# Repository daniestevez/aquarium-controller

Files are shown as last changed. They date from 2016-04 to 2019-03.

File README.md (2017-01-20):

# aquarium-controller
Arduino-based Aquarium controller

[More information](http://destevez.net/electronics-projects/arduino-aquarium-controller/)

Libraries required for the Arduino software:

* Time, DS1307RTC from http://playground.arduino.cc/Code/Time
* Timer from http://playground.arduino.cc/Code/Timer
* Timezone from https://github.com/JChristensen/Timezone
* Keypad from http://playground.arduino.cc/Code/Keypad
* U8glib from https://github.com/olikraus/u8glib
* OneWireNoResistor from https://github.com/bigjosh/OneWireNoResistor

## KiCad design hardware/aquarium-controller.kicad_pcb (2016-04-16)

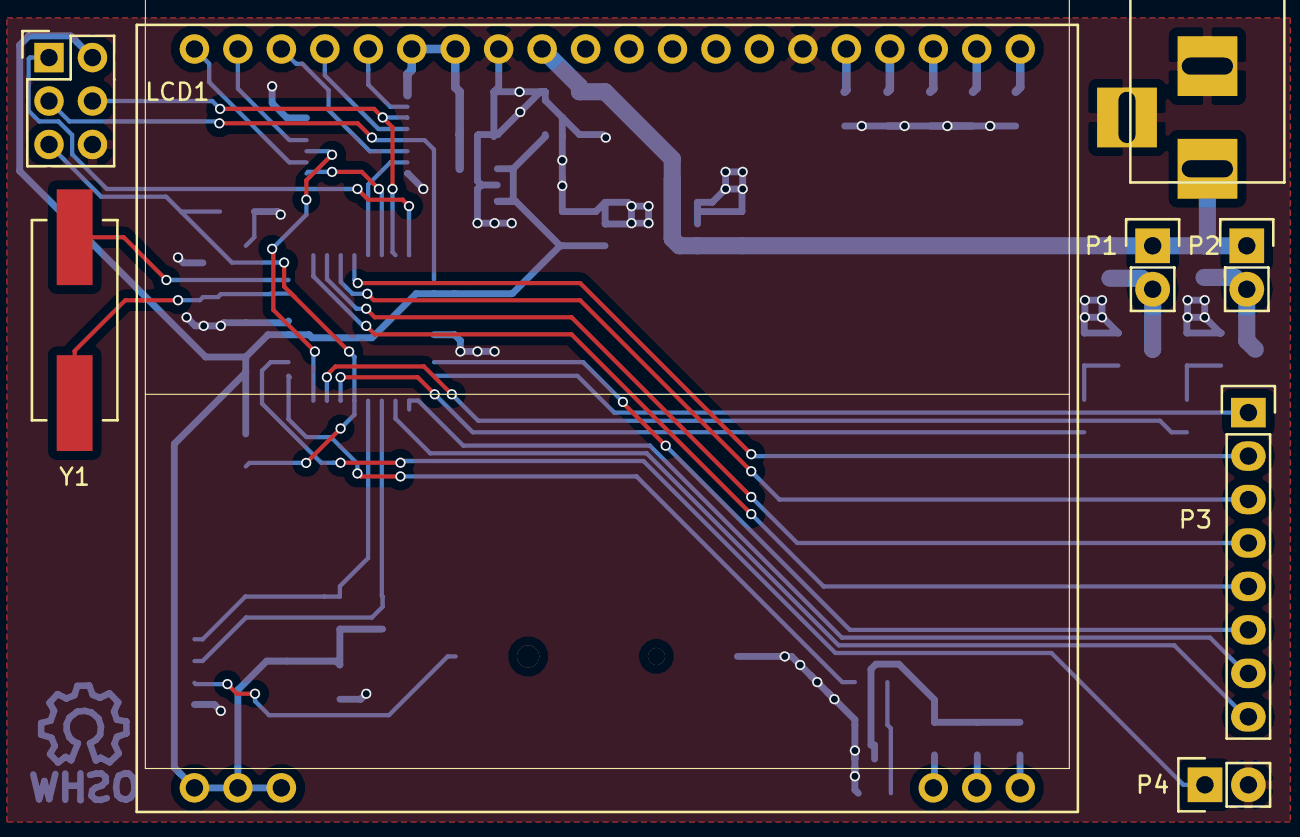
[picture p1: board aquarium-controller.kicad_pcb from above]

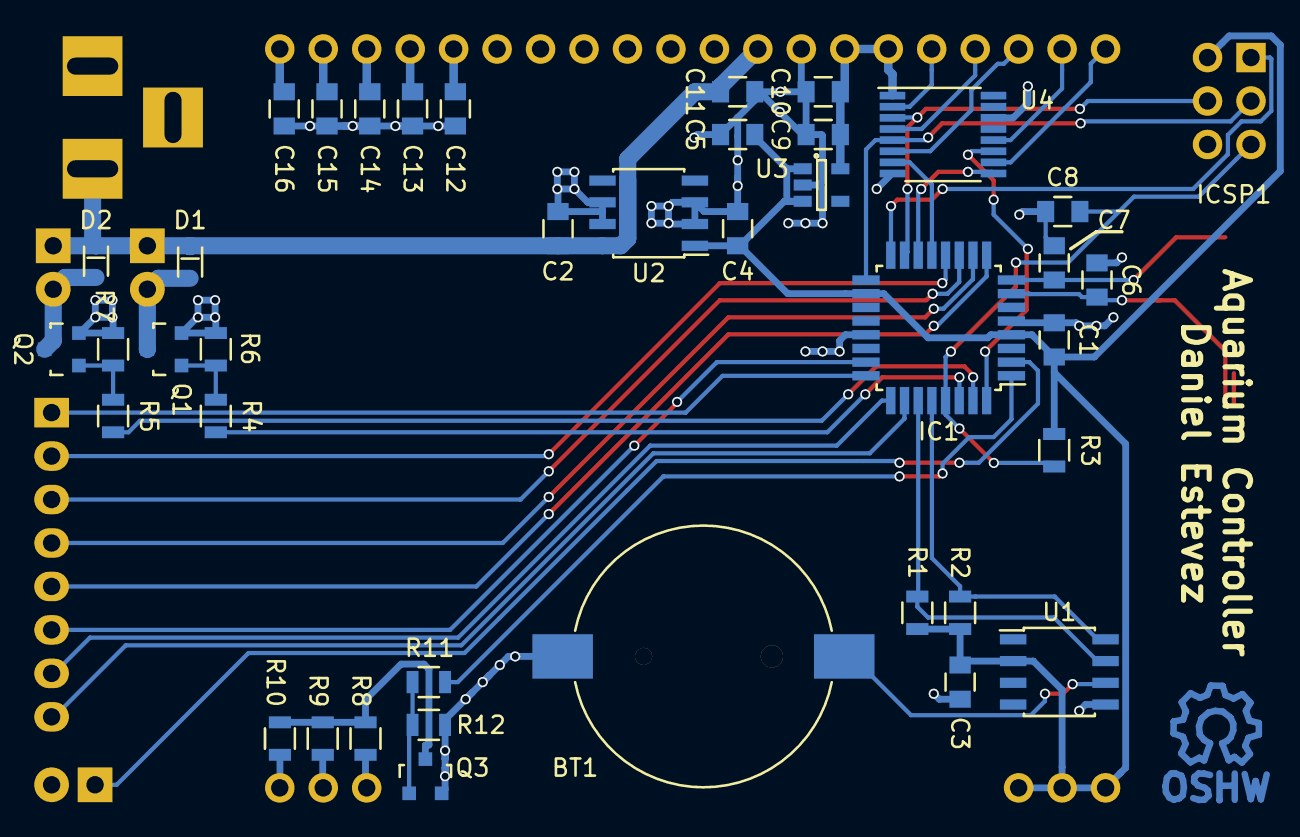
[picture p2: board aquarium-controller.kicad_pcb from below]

Board: 2 copper layers, 47 parts (39 on the bottom side), 47 nets.

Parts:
BT1: Battery; BC501SM
C1, C3, C4, C8, C10: 100n; C_0805
C2: 330n; C_0805
C5, C9, C11, C12, C13, C14, C15, C16: 1u; C_0805
C6, C7: 22p; C_0805
CON1: BARREL_JACK
D1, D2: DB2J20900L; SMini2-F5-B
IC1: ATMEGA328PB; TQFP-32_7x7mm_Pitch0.8mm
ICSP1: AVR-ISP-6; Pin_Header_Straight_2x03
LCD1: DOGM128-6; LED55X46
P1, P2, P4: CONN_01X02; Socket_Strip_Straight_1x02
P3: CONN_01X08; Socket_Strip_Straight_1x08
Q1, Q2, Q3: 2N7002E; SOT-23
R1, R2, R3: 10k; R_0805
R4, R5, R8, R9, R10, R11: 100; R_0805
R6, R7, R12: 100K; R_0805
U1: DS3231M; SOIC-8_3.9x4.9mm_Pitch1.27mm
U2: L78L05ACD; SOIC-8_3.9x4.9mm_Pitch1.27mm
U3: MIC5504; SOT-23-5
U4: 4050; TSSOP-16_4.4x5mm_Pitch0.65mm
Y1: 16MHz; Crystal_HC49-SD_SMD

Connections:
+3V3: C9.1, C10.1, LCD1.34, LCD1.35, U3.5, U4.1
+5V: C1.1, C3.2, C4.1, C5.1, IC1.4, IC1.18, ICSP1.2, LCD1.1, LCD1.2, LCD1.3, R1.1, R2.1, R3.1, U1.2, U2.1, U3.1, U3.3
+12V: C2.1, C11.1, CON1.1, D1.1, D2.1, LCD1.32, P1.1, P2.1, U2.8
/1WIRE: IC1.2, P4.1
/BACKLIGHT: IC1.1, R11.2
/COL1: IC1.26, P3.8
/COL2: IC1.25, P3.7
/COL3: IC1.23, P3.6
/COL4: IC1.9, P3.5
/HEATER: IC1.30, R4.2
/LCDA0: LCD1.38, U4.6
/LCDCS1B: LCD1.40, U4.10
/LCDRST: LCD1.39, U4.12
/LCDSCL: LCD1.37, U4.4
/LCDSI: LCD1.36, U4.2
/LIGHT: IC1.31, R5.2
/ROW1: IC1.10, P3.4
/ROW2: IC1.11, P3.3
/ROW3: IC1.12, P3.2
/ROW4: IC1.24, P3.1
/SCL: IC1.28, R2.2, U1.8
/SDA: IC1.27, R1.2, U1.7
GND: BT1.2, C1.2, C2.2, C3.1, C4.2, C5.2, C6.2, C7.2, C8.2, C9.2, C10.2, C11.2, C12.1, C13.1, C14.1, C15.1, C16.1, CON1.2, CON1.3, IC1.5, IC1.21, ICSP1.6, LCD1.26, LCD1.33, P4.2, Q1.2, Q2.2, Q3.2, R6.2, R7.2, R12.2, U1.5, U2.2, U2.3, U2.6, U2.7, U3.2, U4.8, U4.14
unnamed: BT1.1, U1.6
unnamed: C6.1, IC1.7, Y1.2
unnamed: C7.1, IC1.8, Y1.1
unnamed: C8.1, IC1.29, ICSP1.5, R3.2
unnamed: C12.2, LCD1.25
unnamed: C13.2, LCD1.24
unnamed: C14.2, LCD1.23
unnamed: C15.2, LCD1.22
unnamed: C16.2, LCD1.21
unnamed: D1.2, P1.2, Q1.3
unnamed: D2.2, P2.2, Q2.3
unnamed: IC1.13, U4.7
unnamed: IC1.14, U4.9
unnamed: IC1.15, ICSP1.4, U4.3
unnamed: IC1.16, ICSP1.1
unnamed: IC1.17, ICSP1.3, U4.5
unnamed: IC1.32, U4.11
unnamed: LCD1.18, R8.2
unnamed: LCD1.19, R9.2
unnamed: LCD1.20, R10.2
unnamed: Q1.1, R4.1, R6.1
unnamed: Q2.1, R5.1, R7.1
unnamed: Q3.1, R11.1, R12.1
unnamed: Q3.3, R8.1, R9.1, R10.1

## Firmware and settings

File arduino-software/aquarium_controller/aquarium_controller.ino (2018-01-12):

#include <Event.h>
#include <Timer.h>
#include <Wire.h>

#include <Time.h>

#include <avr/wdt.h>

#include "temperature.h"
#include "feeding.h"

#define TEMPERATURE_INTERVAL 2100
#define PRINCIPAL_INTERVAL 100
#define BACKLIGHT_INTERVAL 40
#define ILLUMINATION_INTERVAL 900
#define HEATER_INTERVAL 9800
#define FEEDING_INTERVAL 1500

Timer timer;

char key_pressed = '\0';

TimeElements time;

boolean notification() {
  return need_feeding;
}

void setup(void) {
  wdt_enable(WDTO_4S);
  
  pinMode(2, INPUT_PULLUP); // unused pin

  boot_backlight();
  boot_interface();
  boot_clock(); // TODO: handle error
  boot_illumination();
  boot_temperatures(); // TODO handle error
  boot_heater();
  boot_feeding();
  
  timer.every(TEMPERATURE_INTERVAL, update_temperatures);
  timer.every(PRINCIPAL_INTERVAL, update_principal);
  timer.every(BACKLIGHT_INTERVAL, update_backlight);
  timer.every(ILLUMINATION_INTERVAL, update_illumination);
  timer.every(HEATER_INTERVAL, update_heater);
  timer.every(FEEDING_INTERVAL, update_feeding);
  
  finish_boot_interface();  
  return;
}

void loop(void) {
  char input;

  wdt_reset();
  
  timer.update();
  
  input = get_input();
  if (input) {
    process_input(input);
  }
}

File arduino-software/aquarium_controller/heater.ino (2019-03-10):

#include <avr/eeprom.h>

#define HEATER_PIN 0

#define HEATER_OFFSET (byte *) 0x300

// 1/8 degree
#define LOW_THRESHOLD 2
// 1/16 degree
#define HIGH_THRESHOLD 1

int heater_temp;
boolean heater_on = false;

void boot_heater() {
  read_heater(&heater_temp);
  heater_on = heater();
  pinMode(HEATER_PIN, OUTPUT);
  digitalWrite(HEATER_PIN, heater_on);
  
  return;
}

void update_heater() {
  if (heater_on != heater()) {
    heater_on = !heater_on;
    digitalWrite(HEATER_PIN, heater_on);
  }
  
  return;
}

void write_heater(int temp) {
  eeprom_write_block((void *) &temp, HEATER_OFFSET, sizeof(int));
  
  return;
}

void read_heater(int *temp) {
  eeprom_read_block((void *) temp, HEATER_OFFSET, sizeof(int));

  return;
}

static boolean heater() {
  if (!temperatures_valid[WATER_SENSOR]) {
    /* temperature sensor is failing. turn the heater off */
    return false;
  }
  if (heater_on && temperatures[WATER_SENSOR] >= heater_temp + HIGH_THRESHOLD)
    return false;
  else if (!heater_on && temperatures[WATER_SENSOR] <= heater_temp - LOW_THRESHOLD)
    return true;

  return heater_on;    
}

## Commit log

2016-04-16 Imported revision A
    [aquarium-controller.kicad_pcb, aquarium-controller.sch]
2016-06-13 Moved Kicad files into hardware folder
    [aquarium-controller.kicad_pcb, aquarium-controller.sch]
2016-06-13 Imported arduino software for the controller
2016-06-13 Updated README with required Arduino libraries
2018-01-09 Moved Arduino files to aquarium_controller folder to please Arduino IDE
2018-01-12 Added compiled firmware and fuses
2018-05-22 Add temperature sensor consistency check
    Do not turn on heater if sensor seems to have failed (i.e., reports a very low temperature)
    [heater.ino]
2019-03-10 Error checking for temperature sensors
    [heater.ino, temperature.h, temperature.ino]
2019-03-10 Corrected typo in interface message
    [interface.ino]
2019-05-12 Fixed bug in temperature sensor CRC check
    [temperature.ino]
